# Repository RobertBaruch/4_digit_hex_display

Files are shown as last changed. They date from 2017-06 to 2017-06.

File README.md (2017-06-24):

# 4_digit_hex_display
A 4-digit hex display.

* Runs off 5V. Draws 30mA with all segments lit.
* Uses Vishay TDSR1060 7-segment displays (the dots are not used).
* Uses ATTINY84A as a 16x7 ROM (requires a programmer).
* See bin2hex.S for pinouts, instructions.
* Bill of materials:
  * 28x 0805 3.3k 1/8W SMD resistors
  * 4x 0805 100k 1/8W SMD resistors
  * 4x 0805 100n 16V or above SMD ceramic capacitors
  * 4x ATTINY84A-SSU (the 14-pin SOIC package)
  * 4x Vishay TDSR1060 7-segment displays
  * 2x 1x10 0.1" pitch pin headers (optional)
  
In the image, it looks like the off segments are slightly lit, but they are actually very very slightly illuminated from the other segments. That's just a camera effect. In actual viewing conditions, the effect is hardly visible. If you wanted to reduce the lumens as well as the current consumption, you might increase the 3.3k resistors.

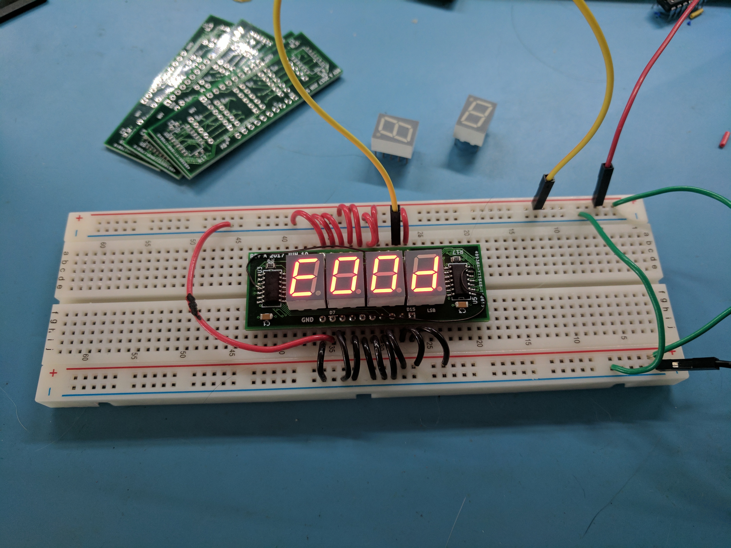
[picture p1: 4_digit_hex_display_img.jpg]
Image of device


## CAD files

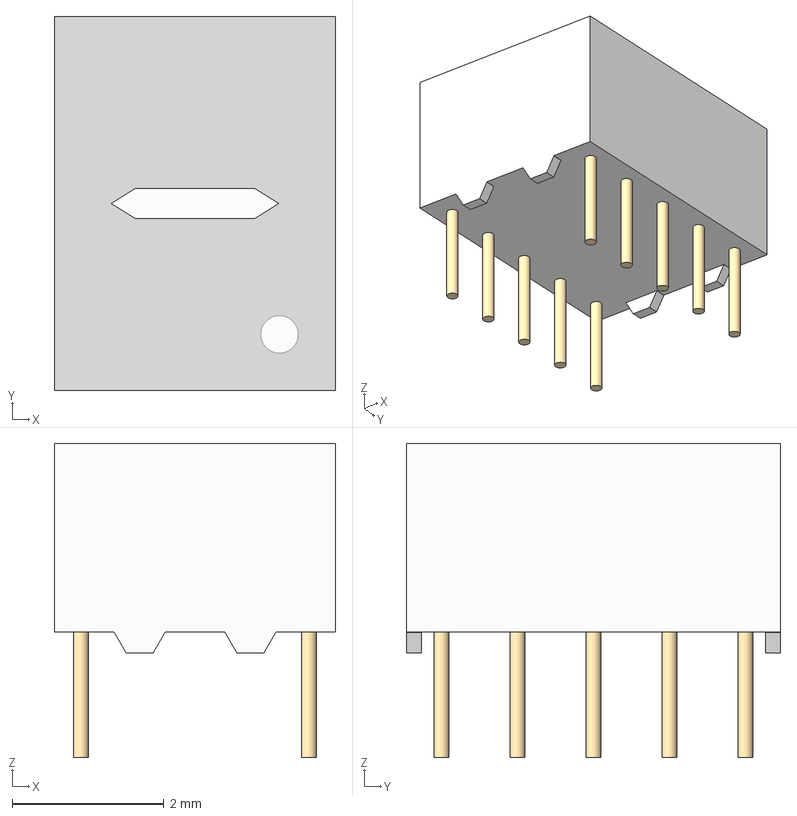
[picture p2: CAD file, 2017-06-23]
TDSR10x0 LED v8.step
3.70 x 4.92 x 4.14 mm

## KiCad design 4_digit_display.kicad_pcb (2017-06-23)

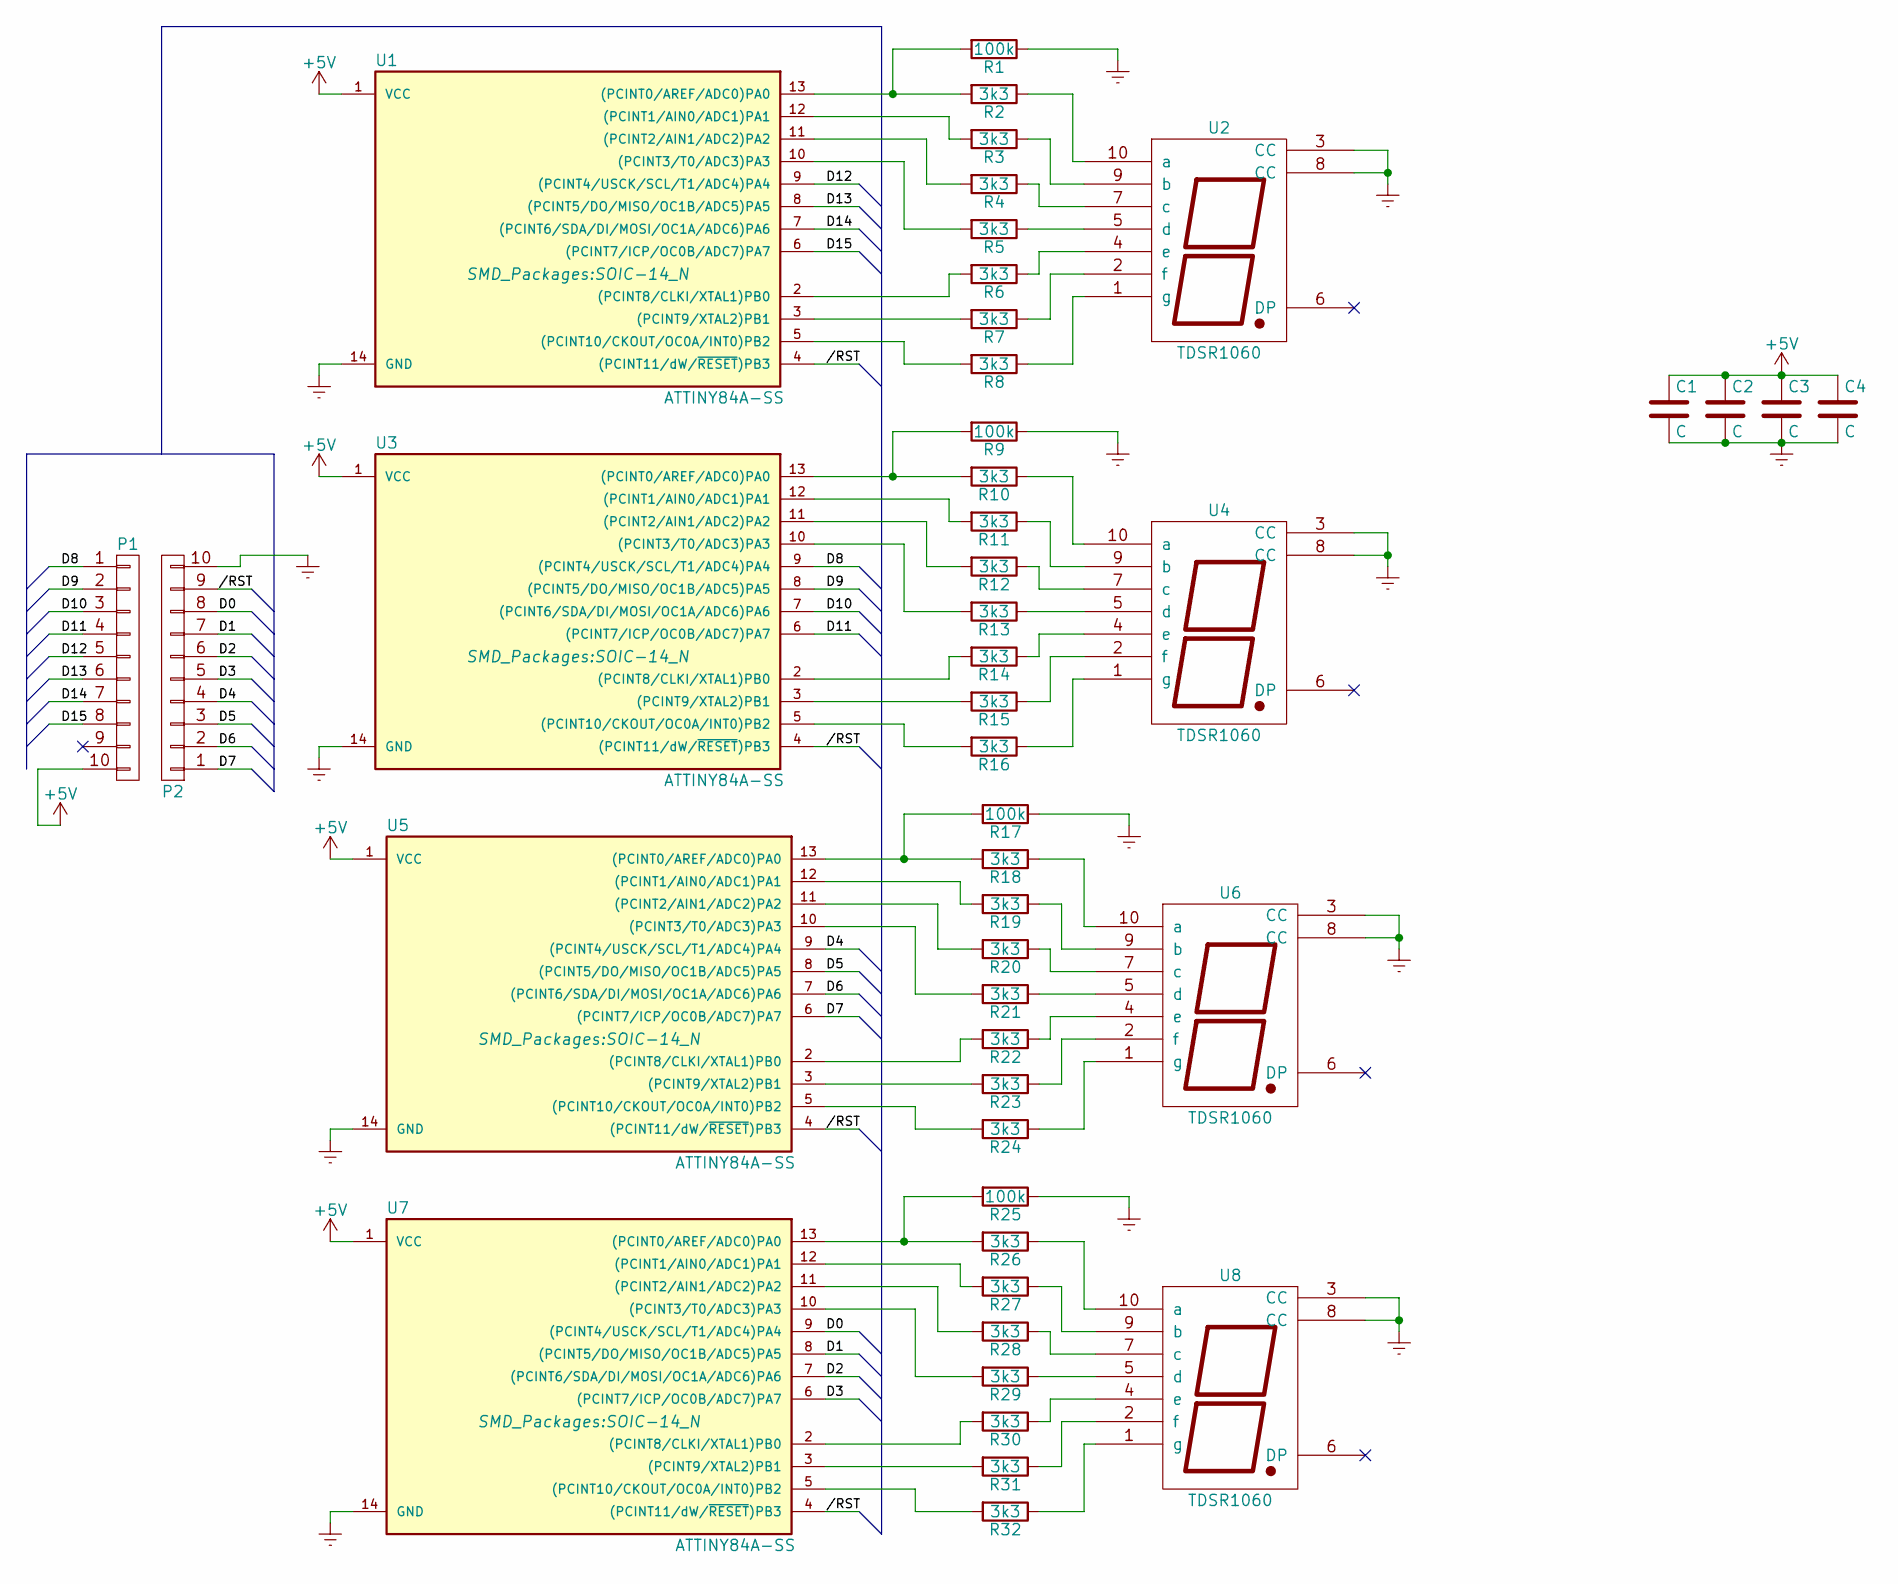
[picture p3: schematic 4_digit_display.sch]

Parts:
C1, C2, C3, C4: C; C_0805
P1, P2: CONN_01X10; Pin_Header_Straight_1x10_Pitch2.54mm
R1, R9, R17, R25: 100k; R_0805
R2, R3, R4, R5, R6, R7, R8, R10, R11, R12, R13, R14, R15, R16, R18, R19, R20, R21, R22, R23, R24, R26, R27, R28, R29, R30, R31, R32: 3k3; R_0805
U1, U3, U5, U7: ATTINY84A-SS; SOIC-14_N
U2, U4, U6, U8: TDSR1060; TDSR10

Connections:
+5V: C1.1, C2.1, C3.1, C4.1, P1.10, U1.1 (VCC), U3.1 (VCC), U5.1 (VCC), U7.1 (VCC)
//RST: P2.9, U1.4 ((PCINT11/dW/~RESET~)PB3), U3.4 ((PCINT11/dW/~RESET~)PB3), U5.4 ((PCINT11/dW/~RESET~)PB3), U7.4 ((PCINT11/dW/~RESET~)PB3)
/D0: P2.8, U7.9 ((PCINT4/USCK/SCL/T1/ADC4)PA4)
/D1: P2.7, U7.8 ((PCINT5/DO/MISO/OC1B/ADC5)PA5)
/D2: P2.6, U7.7 ((PCINT6/SDA/DI/MOSI/OC1A/ADC6)PA6)
/D3: P2.5, U7.6 ((PCINT7/ICP/OC0B/ADC7)PA7)
/D4: P2.4, U5.9 ((PCINT4/USCK/SCL/T1/ADC4)PA4)
/D5: P2.3, U5.8 ((PCINT5/DO/MISO/OC1B/ADC5)PA5)
/D6: P2.2, U5.7 ((PCINT6/SDA/DI/MOSI/OC1A/ADC6)PA6)
/D7: P2.1, U5.6 ((PCINT7/ICP/OC0B/ADC7)PA7)
/D8: P1.1, U3.9 ((PCINT4/USCK/SCL/T1/ADC4)PA4)
/D9: P1.2, U3.8 ((PCINT5/DO/MISO/OC1B/ADC5)PA5)
/D10: P1.3, U3.7 ((PCINT6/SDA/DI/MOSI/OC1A/ADC6)PA6)
/D11: P1.4, U3.6 ((PCINT7/ICP/OC0B/ADC7)PA7)
/D12: P1.5, U1.9 ((PCINT4/USCK/SCL/T1/ADC4)PA4)
/D13: P1.6, U1.8 ((PCINT5/DO/MISO/OC1B/ADC5)PA5)
/D14: P1.7, U1.7 ((PCINT6/SDA/DI/MOSI/OC1A/ADC6)PA6)
/D15: P1.8, U1.6 ((PCINT7/ICP/OC0B/ADC7)PA7)
GNDREF: C1.2, C2.2, C3.2, C4.2, P2.10, R1.1, R9.1, R17.1, R25.1, U1.14 (GND), U2.3 (CC), U2.8 (CC), U3.14 (GND), U4.3 (CC), U4.8 (CC), U5.14 (GND), U6.3 (CC), U6.8 (CC), U7.14 (GND), U8.3 (CC), U8.8 (CC)
unnamed: R1.2, R2.2, U1.13 ((PCINT0/AREF/ADC0)PA0)
unnamed: R2.1, U2.10 (a)
unnamed: R3.1, U2.9 (b)
unnamed: R3.2, U1.12 ((PCINT1/AIN0/ADC1)PA1)
unnamed: R4.1, U2.7 (c)
unnamed: R4.2, U1.11 ((PCINT2/AIN1/ADC2)PA2)
unnamed: R5.1, U2.5 (d)
unnamed: R5.2, U1.10 ((PCINT3/T0/ADC3)PA3)
unnamed: R6.1, U2.4 (e)
unnamed: R6.2, U1.2 ((PCINT8/CLKI/XTAL1)PB0)
unnamed: R7.1, U2.2 (f)
unnamed: R7.2, U1.3 ((PCINT9/XTAL2)PB1)
unnamed: R8.1, U2.1 (g)
unnamed: R8.2, U1.5 ((PCINT10/CKOUT/OC0A/INT0)PB2)
unnamed: R10.1, U4.10 (a)
unnamed: R9.2, R10.2, U3.13 ((PCINT0/AREF/ADC0)PA0)
unnamed: R11.1, U4.9 (b)
unnamed: R11.2, U3.12 ((PCINT1/AIN0/ADC1)PA1)
unnamed: R12.1, U4.7 (c)
unnamed: R12.2, U3.11 ((PCINT2/AIN1/ADC2)PA2)
unnamed: R13.1, U4.5 (d)
unnamed: R13.2, U3.10 ((PCINT3/T0/ADC3)PA3)
unnamed: R14.1, U4.4 (e)
unnamed: R14.2, U3.2 ((PCINT8/CLKI/XTAL1)PB0)
unnamed: R15.1, U4.2 (f)
unnamed: R15.2, U3.3 ((PCINT9/XTAL2)PB1)
unnamed: R16.1, U4.1 (g)
unnamed: R16.2, U3.5 ((PCINT10/CKOUT/OC0A/INT0)PB2)
unnamed: R17.2, R18.2, U5.13 ((PCINT0/AREF/ADC0)PA0)
unnamed: R18.1, U6.10 (a)
unnamed: R19.1, U6.9 (b)
unnamed: R19.2, U5.12 ((PCINT1/AIN0/ADC1)PA1)
unnamed: R20.1, U6.7 (c)
unnamed: R20.2, U5.11 ((PCINT2/AIN1/ADC2)PA2)
unnamed: R21.1, U6.5 (d)
unnamed: R21.2, U5.10 ((PCINT3/T0/ADC3)PA3)
unnamed: R22.1, U6.4 (e)
unnamed: R22.2, U5.2 ((PCINT8/CLKI/XTAL1)PB0)
unnamed: R23.1, U6.2 (f)
unnamed: R23.2, U5.3 ((PCINT9/XTAL2)PB1)
unnamed: R24.1, U6.1 (g)
unnamed: R24.2, U5.5 ((PCINT10/CKOUT/OC0A/INT0)PB2)
unnamed: R25.2, R26.2, U7.13 ((PCINT0/AREF/ADC0)PA0)
unnamed: R26.1, U8.10 (a)
unnamed: R27.1, U8.9 (b)
unnamed: R27.2, U7.12 ((PCINT1/AIN0/ADC1)PA1)
unnamed: R28.1, U8.7 (c)
unnamed: R28.2, U7.11 ((PCINT2/AIN1/ADC2)PA2)
unnamed: R29.1, U8.5 (d)
unnamed: R29.2, U7.10 ((PCINT3/T0/ADC3)PA3)
unnamed: R30.1, U8.4 (e)
unnamed: R30.2, U7.2 ((PCINT8/CLKI/XTAL1)PB0)
unnamed: R31.1, U8.2 (f)
unnamed: R31.2, U7.3 ((PCINT9/XTAL2)PB1)
unnamed: R32.1, U8.1 (g)
unnamed: R32.2, U7.5 ((PCINT10/CKOUT/OC0A/INT0)PB2)

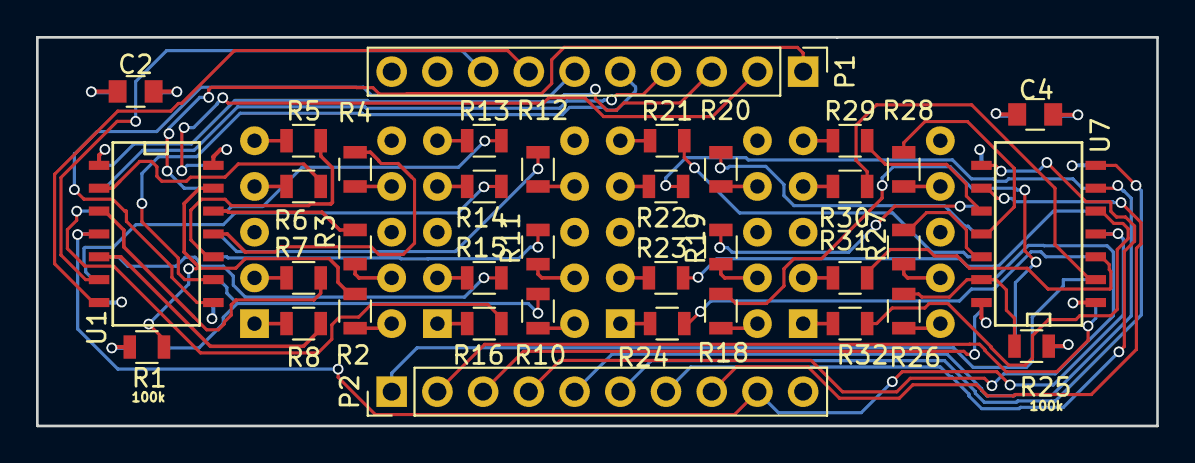
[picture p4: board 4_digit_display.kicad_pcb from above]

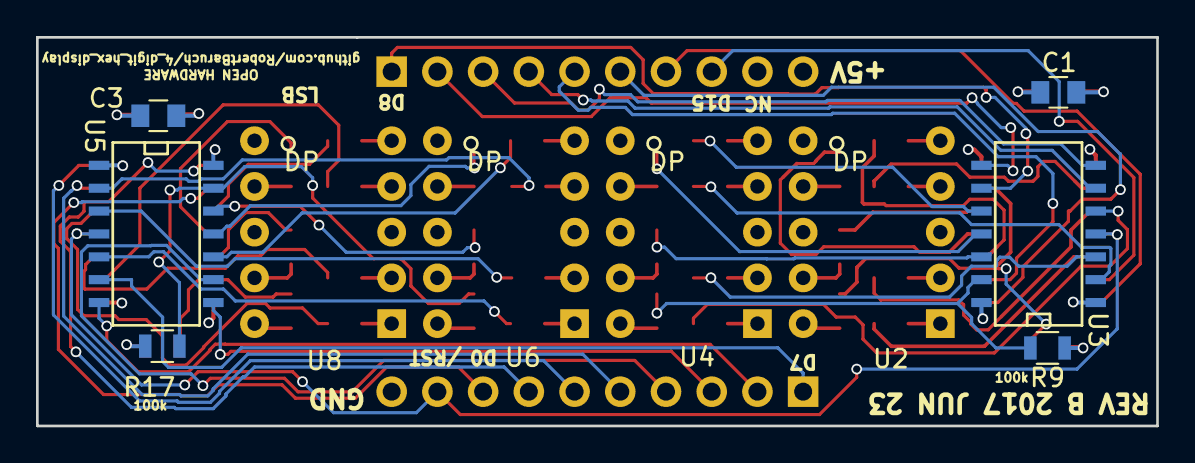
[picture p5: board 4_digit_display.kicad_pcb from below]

Board: 4 copper layers, 62.2 x 21.6 mm, 46 parts (10 on the bottom side), 75 nets.

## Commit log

2017-06-23 Rev B dump
    [4_digit_display.kicad_pcb, 4_digit_display.sch, TDSR10x0 LED v8.step]
2017-06-23 Added BOM
